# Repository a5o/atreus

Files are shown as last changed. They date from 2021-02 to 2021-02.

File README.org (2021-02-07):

*Note to this fork*: I slightly modified the case to use threaded rivet nuts for a cleaner look. 
See the folder case/openscad_atreus62_with_rivets/ for details. 

I want to thank to the original developer (technomancy) for the great work.

* Atreus Keyboard

This repository is [[https://gitlab.com/technomancy/atreus][moved to GitLab]].

The Atreus is a mechanical keyboard designed primarily to match the
shape of human hands and to be as portable as possible. The case
measures 26x12cm and lacks even a number row, relying heavily upon the
=fn= key. There is a circuit board for this design, but it's also
possible to [[http://wiki.geekhack.org/index.php?title=Hard-Wiring_How-To][manually wire the matrix]].

I've seen a number of existing DIY 40% keyboard designs, but most of
them stagger the rows, which I find very annoying now that I've gotten
used to the columnar layout of the [[https://geekhack.org/index.php?topic=22780.0][Ergodox]]. In addition, many of the
designs I've seen waste a lot of room on the space bar, failing to
take into account the fact that the thumb is the strongest and most
versatile of the fingers. This design avoids both these problems while
taking a more couch-friendly single-piece approach.



See [[./changelog.md][the changelog]] for the various revisions made to the design since
its initial release.

** Kits

You can buy [[http://atreus.technomancy.us][Atreus kits]] that have all the parts you need along with
detailed assembly instructions from http://atreus.technomancy.us. If
you'd rather round up all the parts yourself, that's possible too
since the design is completely open source; see the bill of materials
below.

** Layout

Only a handful of punctuation marks (and no digits) are available
unshifted, and all the modifiers are on the bottom row:

 :    q     w     e     r     t       ||       y     u     i     o    p
 :    a     s     d     f     g       ||       h     j     k     l    ;
 :    z     x     c     v     b       ||       n     m     ,     .    /
 :   esc   tab  super shift bksp ctrl || alt space  fn     -     '  enter

The numbers and most of the punctuation are on the fn layer with a
numpad-style arrangement under the right hand:

 :    !    @     up     {    }        ||     pgup    7     8     9    *
 :    #  left   down  right  $        ||     pgdn    4     5     6    +
 :    [    ]      (     )    &        ||       `     1     2     3    \
 :   L2  insert super shift bksp ctrl || alt space   fn    .     0    =

The =L2= key switches it to the function layer, and tapping =L0= here
brings it back to the first layer.

 :  insert home    ↑    end  pgup     ||       ↑     F7    F8    F9   F10
 :    del   ←      ↓     →   pgdn     ||       ↓     F4    F5    F6   F11
 :                           reset    ||             F1    F2    F3   F12
 :              super shift bksp ctrl || alt space   L0             

The [[https://atreus.technomancy.us/download][firmware]] includes a number of other options, including
colemak and dvorak. [[https://atreus.technomancy.us/qmk][Customizing your layout]] is easy to do with the QMK configurator interface.

** Parts

*** Switches

This layout has five modifiers and 37 non-modifiers.

I strongly prefer the feel and sound of tactile [[https://deskthority.net/wiki/Matias_switch#Click][Matias Clicky]]
switches for typing. However, I like having [[https://deskthority.net/wiki/Matias_switch#Linear][Matias Linear
switches]] switches on the modifier keys (ctrl, alt, super, shift, and
fn) because the tactile effect has no benefit for keys that are held
down, and giving a different response helps you learn the layout more
quickly.

For users that need to operate in sound-sensitive environments like
open offices or libraries,
[[http://deskthority.net/wiki/Matias_switch#Quiet_click][Matias Quiet
Click]] switches are a popular choice since they still offer tactility
without the noise. Other users prefer switches in the
[[http://deskthority.net/wiki/Cherry_MX][Cherry MX]] family, which use
different keycaps and switch plates but still work fine.

*** Diodes

In order to avoid ghosting, each switch needs a diode. The [[https://www.radioshack.com/product/index.jsp?productId=2062587][1N4148]] is a
readily-available choice, but nearly any signal diode would work.

*** Microcontroller

The circuit board design uses a [[http://www.pololu.com/product/3101][Pololu A-star micro]]. Hand-wired boards
can also use a [[http://arduino.cc/en/Main/ArduinoBoardMicro][Arduino Pro Micro]].

Be sure to get a microcontroller without headers so it will fit in
between the bottom layer and the plate. USB micro is preferred over
USB mini for this reason as well.

*** Keycaps

Caps for Matias switches are included in the official kits. Sculpted
caps are also available [[http://matias.ca/order/#keycaps][from Matias]] or by harvesting from old Alps
keyboards. It's recommended that you use unlabeled keys, because due
to the different sizes and orientations of certain keys (backspace,
shift, enter, etc) many of the labels will be incorrect if present.

Cherry switches have more options. This
[[http://pimpmykeyboard.com/dsa-pbt-abs-blank-keycap-sets/][DSA-shaped base set]] (spherical indentations on the key, same profile for each
row) from Signature Plastics has 52 1x keys plus a few extras we won't
use. There are two "deep dish" keys in that set which you can place
under your index fingers on the home row to help guide your hands to
the right spot without looking. However, you only get a single 1.5x
keycap, and the middle two thumb keys both use them, so you might want
to pick up an extra.

** Circuit Board

The =atreus.rkt= program calculates switch and diode positions based
on row/column counts, spacing, and rotation factors, and emits a
=atreus.kicad_pcb= file. The board outline and traces are done by hand
and are stored in the =header.rktd= and =traces.rktd= files
respectively. The =atreus.kicad_pcb= file can be imported into [[http://kicad-pcb.org][Kicad]]
which can export Gerber files suitable for fabrication. A copy of the
Kicad PCB file is included in the repository if you don't want to
recompile it using Racket. Recompiling is only required if you want to
make changes to the procedurally-generated portions of the board.

Unfortunately most PCB fabricators require a minimum order of 10 or
so, making this impractical for one-offs. The PCB is not required, so
for one-off boards it's usually more sensible to stick with a [[http://atreus.technomancy.us/assembly-hand-wired.pdf][hand-wired build]] instead.

** Case

Layered laser-cut wood or acrylic. The [[http://geekhack.org/index.php?topic%3D54759.msg1304117#msg1304117][mark II case]] (EPS files in the
=case/= directory) features 8 screw holes and a kind of "stair step"
design around the top and bottom of the key clusters; mark I has
straight lines.

The files =alps-top-plate-3mm.eps=, =alps-switch-plate-3mm.eps=, and
=bottom-plate-3mm.eps= are to be cut in 3mm acrylic or wood. The
=spacer.eps= file can be cut on something thicker; between 4.5mm and
6mm is recommended. Alternatively you can cut it in 3mm twice. The
spacer needs to be at least as thick as the connector of the USB cable
you're using. If you are using Cherry switches, you should use
=cherry-3mm.eps= for the top, switch, and bottom plates instead, but
the spacer is the same.

There is also a programmatically-implemented version of the case
written in OpenSCAD; it is more flexible (you can tweak the number of
rows/cols, etc and recompile) but it doesn't match the canonical case
exactly; in particular the screw holes are placed differently.

The original case (=case-mk-i.svg=) design is also included; it is
slightly less wide and has a minor asymmetry with the screws on the
bottom side.

On a 100W Epilog laser, the 3mm layers cut in about a minute and a
half. I did a run with 6mm acrylic of the other layers which took
nearly 6 minutes.

Wood cases should be finished with sandpaper and lacquer, shellac, or polyurethane.

** Firmware

The [[https://qmk.fm][QMK firmware]] is
recommended. [[https://atreus.technomancy.us/download][Standard
layouts]] are available precompiled, or you can
[[https://atreus.technomancy.us/qmk][design your own]] in the
configurator.

There is also the older
[[https://github.com/technomancy/atreus-firmware][atreus-firmware]]
custom codebase which works but has fewer features. It is recommended
mostly for learning purposes since the code is much simpler and easier
to understand than QMK. Previously TMK was the recommended choice for
firmware, but QMK has much better documentation and ease of use and is
now recommended.

** Bill of Materials

If you don't want to get [[https://atreus.technomancy.us][the kit]] you can source parts yourself. (You
can also order a partial kit if you want to customize some of the
parts.) Using Cherry switches is cheapest unless you can find cheap
Alps-mount keycaps:

- 50 Matias or Cherry switches from mechanicalkeyboards.com
- 50 diodes from radio shack, ebay, or whatever
- 40 1x, 2 1.5x Keycaps from signatureplastics.com OR full keycap set from matias.ca
- A-star micro from pololu.com
- Case materials from various sources
- Case laser cutting: 7.5 minutes on a 100W Epilog laser; varies by source
- USB micro cable, get anywhere

Recommended but optional:

- 5 linear Matias or Cherry switches

The base keycap set from Signature Plastics only has one 1.5x key,
which is used for the inner thumb keys. You can use a 1x key for one
of them, but it looks kind of tacky, so I recommend getting a second
1.5x keycap separately.

*** Other Tools

You'll need a soldering iron, solder, and a wire cutter. A multimeter
can come in handy for testing the connections but is optional. You'll
also need eight M3 machine screws with nuts; the length of the screws
depends on the thickness of the acrylic you use. You can add rubber
feet to the bottom to prevent the board from sliding around when
placed on a desk. You'll also need sandpaper and lacquer for the
wooden case.

If you are building a hand-wired board you will also need a glue gun,
hookup wire, and wire strippers.

** Assembly

See the [[https://atreus.technomancy.us/assembly.pdf][assembly instructions]] PDF.

Hand-wired boards will want the [[https://atreus.technomancy.us/assembly-hand-wired.pdf][previous edition of the assembly instructions]].

The LaTeX source to the assembly instructions is in the =assembly= directory.

** Inspiration

These fine projects all provided inspiration for various aspects of
the Atreus, as well as the folks on the =#geekhack= freenode channel.

- [[https://geekhack.org/index.php?topic=22780.0][Ergodox]]
- [[http://deskthority.net/workshop-f7/onehand-20-keyboard-t6617.html][OneHand]]
- [[http://blog.fsck.com/2013/12/better-and-better-keyboards.html][keyboard.io]]
- [[http://geekhack.org/index.php?topic=48718][ErgoT]]

** Builds

If you've built an Atreus, please add your name to [[https://github.com/technomancy/atreus/wiki/BuildLogs][the build logs wiki]].

There's also a [[https://atreus.technomancy.us/list][mailing list]] for people who have built or ordered an
Atreus or are interested in doing so.

** Orestes

An [[https://www.flickr.com/photos/technomancy/14654421878][experimental build]] uses the [[http://pjrc.com/store/teensy31.html][Teensy 3]] microcontroller and
ARM [[https://github.com/technomancy/orestes/tree/teensy3][Forth-based]] firmware, but this is not really suitable for general-purpose use; it's more of a curiosity.

** License

Copyright © 2014-2018 Phil Hagelberg and contributors

Released under the [[https://www.gnu.org/licenses/gpl.html][GNU GPL version 3]]

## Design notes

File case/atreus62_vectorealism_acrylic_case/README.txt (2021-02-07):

IMPORTANT: the case was designed considering 3mm layers, however
due to variation in thickness some of the spacer layers were
nearer to 2.5mm. Because of this the rivets needed some rubber
washers to get a proper closing of the case. A solution would be
to substitute the third layer with small holes with a layer with
the larger holes.

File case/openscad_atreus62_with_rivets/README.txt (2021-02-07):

Modified atreus(62) case to use threaded rivet nut inserts on the
bottom of the case for a neater look. Following parameters must
be adjusted depending on size of screws and laser cutter kerf:

 - screw_hole_radius
 - rivets_hole_radius
 - switch_plate_hole_radius
 - switch_hole_size

I added an additional variable for switch plate screw hole radius
as, in my case, the company cutting the plate (laserboost) didn't
want a kerf set, while the company cutting the acrylic layer
wanted a kerf of 0.2. Please adjust as needed.

dxf file ready for laserboost in directory
atreus62_laserboost_steel_plate.

svg file ready for vectorealism in directory
atreus62_vectorealism_acrylic_case.

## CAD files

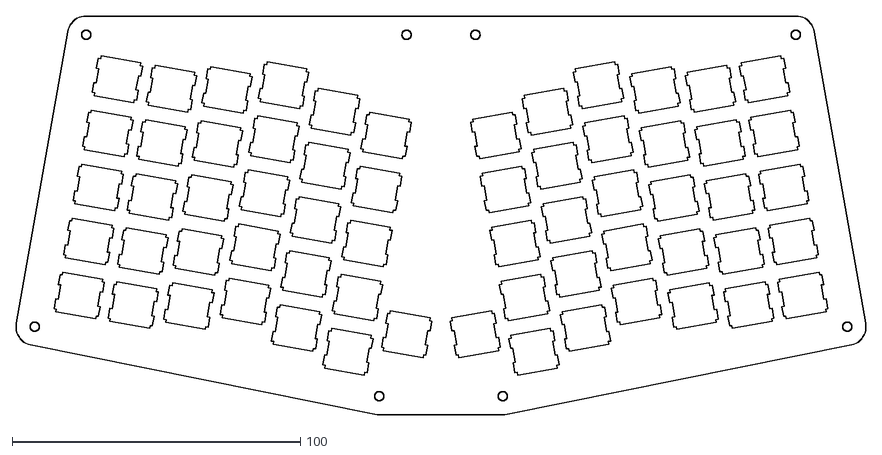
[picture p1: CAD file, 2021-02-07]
case/atreus62_laserboost_steel_plate/atreus62_plate.dxf
295.0 x 138.5

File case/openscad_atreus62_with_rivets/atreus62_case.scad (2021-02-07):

// -*- mode: c -*-
/* All distances are in mm. */

/* set output quality */
$fn = 50;

/* set to true to render as 3D */
render3d = false;

/* set to true to output only the switch_plate */
switch_plate_only = false;

/* Distance between key centers. */
column_spacing   = 19.05;
row_spacing      = column_spacing;

/* This number should exceed row_spacing and column_spacing. The
 default gives a 1mm = (20mm - 19mm) gap between keycaps and cuts in
 the top plate.*/
key_hole_size = 20.05;

/* rotation angle; the angle between the halves is twice this
   number */
angle = 10;

/* The radius of screw holes. Holes will be slightly bigger due
   to the cut width. */
screw_hole_radius = 1.5; // holes for M3 screws (kerf=0.2) 
rivets_hole_radius = 2.45; // rivets hole sizes (kerf=0.2)
/* Each screw hole is a hole in a "washer". How big these "washers"
   should be depends on the material used: this parameter and the
   `switch_hole_size` determine the spacer wall thickness. */
switch_plate_hole_radius = 1.6; // hole for steel swith plate (no kerf)

washer_radius     = 4 * screw_hole_radius + 0.5;

/* This constant allows tweaking the location of the screw holes near
   the USB cable. Only useful with small `angle` values. Try the value
   of 10 with angle=0. */
back_screw_hole_offset = 0;

/* Distance between halves. */
hand_separation        = 0;

/* The approximate size of switch holes. Used to determine how
   thick walls can be, i.e. how much room around each switch hole to
   leave. See spacer(). */
switch_hole_size = 14;

/* Sets whether the case should use notched holes. As far as I can
   tell these notches are not all that useful... */
use_notched_holes = true;

/* Number of rows and columns in the matrix. You need to update
   staggering_offsets if you change n_cols. */
n_rows = 5;
n_cols = 6;

/* Number of thumb keys (per hand), try 1 or 2. */
n_thumb_keys = 1;

/* The width of the USB cable hole in the spacer. */
cable_hole_width = 14;

/* Vertical column staggering offsets. The first element should
   be zero. */
staggering_offsets = [0, 5, 11, 6, 3, 3];

/* Whether or not to split the spacer into quarters. */
quarter_spacer = true;

/* Where the top/bottom split of a quartered spacer will be. */
spacer_quartering_offset = 60;

module rz(angle, center=undef) {
  /* Rotate children `angle` degrees around `center`. */
  translate(center) {
    rotate(angle) {
      translate(-center) {
        for (i=[0:$children-1])
          children(i);
      }
    }
  }
}

/* Compute coordinates of a point obtained by rotating p angle degrees
   around center. Used to compute locations of screw holes near the
   USB cable hole. */
function rz_fun(p, angle, center) = [cos(angle) * (p[0] - center[0]) - sin(angle) * (p[1] - center[1]) + center[0],
                                     sin(angle) * (p[0] - center[0]) + cos(angle) * (p[1] - center[1])+ center[1]];

module switch_hole(position, notches=use_notched_holes) {
  /* Cherry MX switch hole with the center at `position`. Sizes come
     from the ErgoDox design. */
  hole_size    = 14; //13.97;
  notch_width  = 3.5001;
  notch_offset = 4.2545;
  notch_depth  = 0.8128;
  translate(position) {
    union() {
      square([hole_size, hole_size], center=true);
      if (notches == true) {
        translate([0, notch_offset]) {
          square([hole_size+2*notch_depth, notch_width], center=true);
        }
        translate([0, -notch_offset]) {
          square([hole_size+2*notch_depth, notch_width], center=true);
        }
      }
    }
  }
};

module regular_key(position, size) {
  /* Create a hole for a regular key. */
  translate(position) {
    square([size, size], center=true);
  }
}

module thumb_key(position, size) {
  /* Create a hole for a 1x1.5 unit thumb key. */
  translate(position) {
    scale([1, 1.5]) {
      translate(-position) {
        regular_key(position, size);
      }
    }
  }
}

module column (bottom_position, switch_holes, key_size=key_hole_size) {
  /* Create a column of keys. */
  translate(bottom_position) {
    for (i = [0:(n_rows-1)]) {
      if (switch_holes == true) {
        switch_hole([0, i*column_spacing]);
      } else {
        regular_key([0, i*column_spacing], key_size);
      }
    }
  }
}

module rotate_half() {
  /* Rotate the right half of the keys around the top left corner of
     the thumb key. Assumes that the thumb key is a 1x1.5 key and that
     it is shifted 0.5*column_spacing up relative to the nearest column. */
  rotation_y_offset = 1.75 * column_spacing;
  for (i=[0:$children-1]) {
    rz(angle, [hand_separation, rotation_y_offset]) {
      children(i);
    }
  }
}

module add_hand_separation() {
  /* Shift everything right to get desired hand separation. */
  for (i=[0:$children-1]) {
    translate([0.5*hand_separation, /* we get back the full separation
                                       because of mirroring */
               0]) children(i);
  }
}

module right_half (switch_holes=true, key_size=key_hole_size) {
  /* Create switch holes or key holes for the right half of the
     keyboard. Different key_sizes are used in top_plate() and
     spacer(). */
  x_offset = 0.5 * row_spacing;
  y_offset = 0.5 * column_spacing;
  thumb_key_offset = y_offset + 0.5 * column_spacing;
  rotate_half() {
    add_hand_separation() {
      for (j=[0:(n_thumb_keys-1)]) {
        if (switch_holes == true) {
          switch_hole([x_offset + j*row_spacing, thumb_key_offset]);
        } else {
          thumb_key([x_offset + j*row_spacing, thumb_key_offset], key_size);
        }
      }
      for (j=[0:(n_cols-1)]) {
        column([x_offset + (j+n_thumb_keys)*row_spacing, y_offset + staggering_offsets[j]], switch_holes, key_size);
      }
    }
  }
}

module screw_hole(radius, offset_radius, position, direction) {
  /* Create a screw hole of radius `radius` at a location
     `offset_radius` from `position`, (diagonally), in the direction
     `direction`. Oh, what a mess this is. */
  /* direction is the 2-element vector specifying to which side of
     position to move to, [-1, -1] for bottom left, etc. */

  /* radius_offset is the offset in the x (or y) direction so that
     we're offset_radius from position */
  radius_offset = offset_radius / sqrt(2);
  /* key_hole_offset if the difference between key spacing and key
     hole edge */
  key_hole_offset = 0.5*(row_spacing - key_hole_size);
  x = position[0] + (radius_offset - key_hole_offset) * direction[0];
  y = position[1] + (radius_offset - key_hole_offset) * direction[1];
  translate([x,y]) {
    circle(radius);
  }
}

module right_screw_holes(hole_radius) {
  /* coordinates of the back right screw hole before rotation... */
  back_right = [(n_cols+n_thumb_keys)*row_spacing,
               staggering_offsets[n_cols-1] + n_rows * column_spacing];
  /* and after */
  tmp = rz_fun(back_right, angle, [0, 2.25*column_spacing]);

  nudge = 0.75;

  rotate_half() {
    add_hand_separation() {
      screw_hole(hole_radius, washer_radius,
                 [row_spacing, 0],
                 [-nudge, -nudge]);
      screw_hole(hole_radius, washer_radius,
                 [(n_cols+n_thumb_keys)*row_spacing, staggering_offsets[n_cols-1]],
                 [nudge, -nudge]);
      screw_hole(hole_radius, washer_radius,
                 back_right,
                 [nudge, nudge]);
    }
  }

  /* add the screw hole near the cable hole */
  translate([washer_radius - tmp[0] - 0.5*hand_separation + 4, // 1 added to increase the usb size width
             back_screw_hole_offset]) {
    rotate_half() {
      add_hand_separation() {
        screw_hole(hole_radius,
                   washer_radius,
                   back_right,
                   [nudge, nudge]);
      }
    }
  }
}

module screw_holes(hole_radius) {
  /* Create all the screw holes. */
  right_screw_holes(hole_radius);
  mirror ([1,0,0]) { right_screw_holes(hole_radius); }
}

module left_half(switch_holes=true, key_size=key_hole_size) {
  mirror ([1,0,0]) { right_half(switch_holes, key_size); }
}

module bottom_plate() {
  /* bottom layer of the case */
  difference() {
    hull() { screw_holes(washer_radius); }
    screw_holes(rivets_hole_radius);
  }
}

module template_layer(external_radius,hole_radius) {
  /* template for intermediate layers */
  difference() {
    hull() { screw_holes(external_radius); }
    screw_holes(hole_radius);
  }
}

module top_plate() {
  /* top layer of the case */
  difference() {
    //bottom_plate();
		template_layer(washer_radius,screw_hole_radius);
    right_half(false);
    left_half(false);
  }
}

module switch_plate() {
  /* the switch plate */
  difference() {
    //bottom_plate();
    template_layer(washer_radius, switch_plate_hole_radius);
    right_half();
    left_half();
  }
}
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
